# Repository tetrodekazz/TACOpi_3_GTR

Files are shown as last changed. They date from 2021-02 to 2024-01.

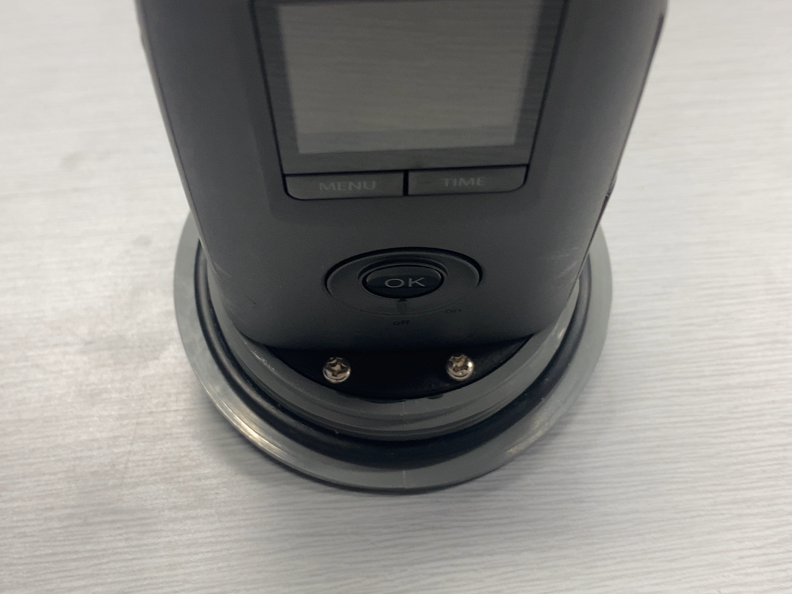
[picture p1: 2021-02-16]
screws_to_fix_camera.jpg

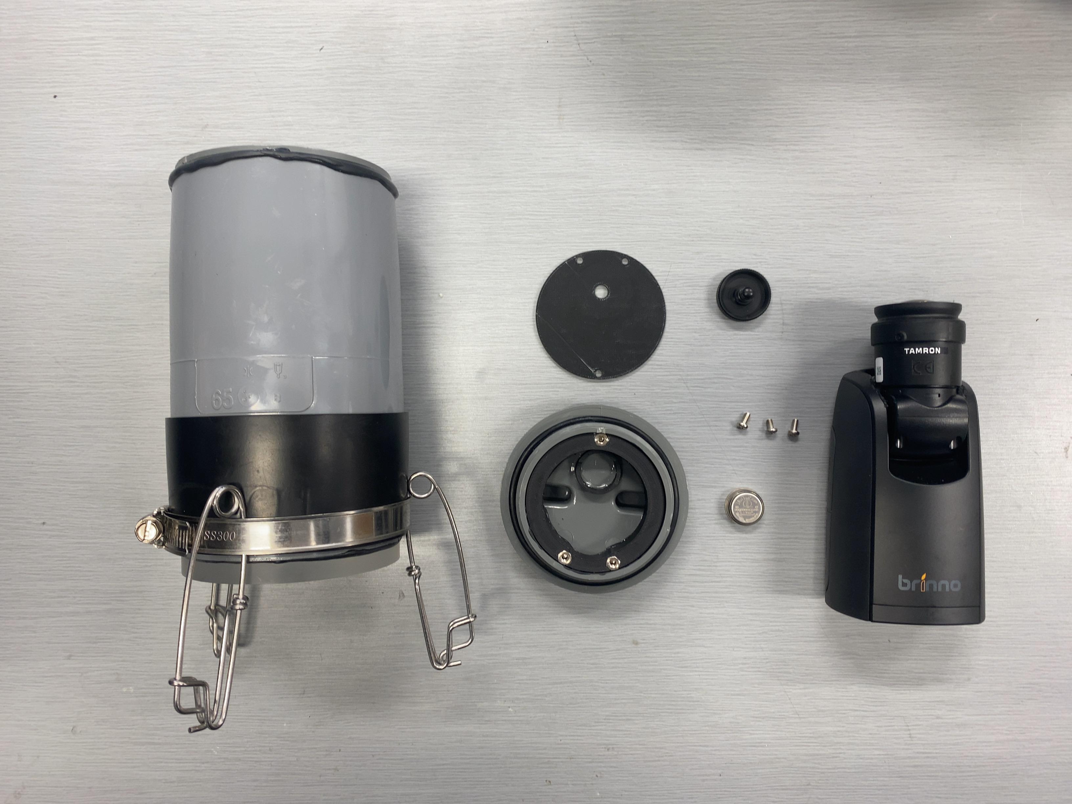
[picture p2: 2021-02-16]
all_parts.jpg

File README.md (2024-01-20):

# TACOpi_3_GTR
「TACOpi 3 GTR」は、ミズダコ漁のモニタリングのために開発された時系列撮影カメラです。
本当の名前は「Transportable Automatic Camera Observatory for Picture Integration ver.3 with a Generic Temperature Recorder」といいますが、長いのでタコパイと呼ばれています。

タコパイは、元々はRaspberry piとカメラモジュールを使用した動画撮影カメラでしたが、漁師さんが手軽に扱えることと、夜間を除き30秒間隔の時系列スチル撮影を2週間以上行えることを開発の目標としたため、途中市販の時系列カメラに載せ替え、耐圧容器も簡便化しました。

この耐圧容器は、手塚（2018）によって発表されたものの部品を変更して小型化したものですが、JAMSTECの中型高圧試験水槽で耐圧試験を行い、水深50mでも圧壊や水漏れを起こさないことが確認されています。実際に、複数回モニタリング調査に用いましたが、これまでに破損したものは皆無でした。

タコパイの製作に関する情報をオープンソースとして公開いたします。ご参考までに、部品リスト、写真のほか、3Dプリンタによる出力が必要な部品の3D CADデータを掲載します。製作方法は後ほどupload予定です（小栗一将）。

なお、タコパイの開発は文部科学省「東北マリンサイエンス拠点形成事業（海洋生態系の調査研究）」（Grant number JPMXD1111105259; https://www.jamstec.go.jp/i-teams/ ）の助成を受け行われました。

引用：手塚尚明（2018）防水ハウジング　塩ビ配管用品で防水ハウジングを作ってみましょう. http://feis.fra.affrc.go.jp/seika/tayousei/fishdiv/housing.html

小栗一将（南デンマーク大学/海洋研究開発機構）

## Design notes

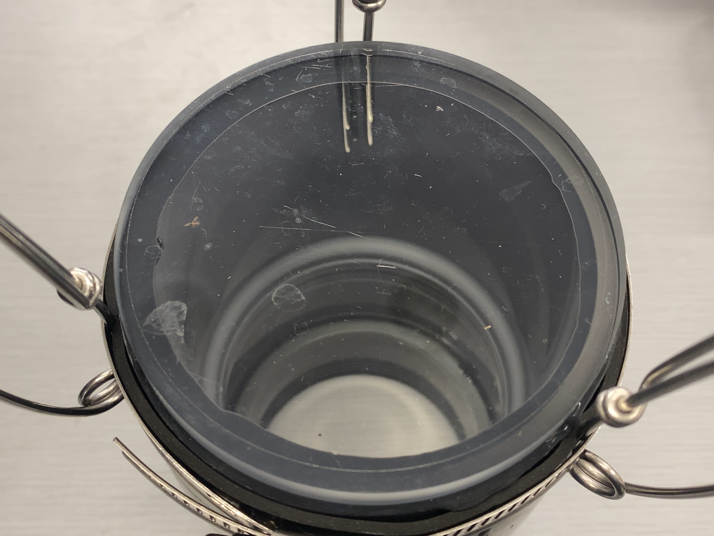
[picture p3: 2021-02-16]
front.jpg

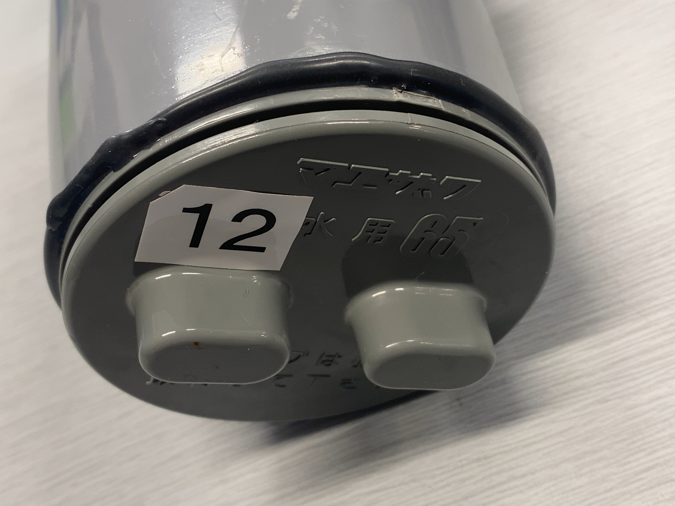
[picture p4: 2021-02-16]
lid.jpg

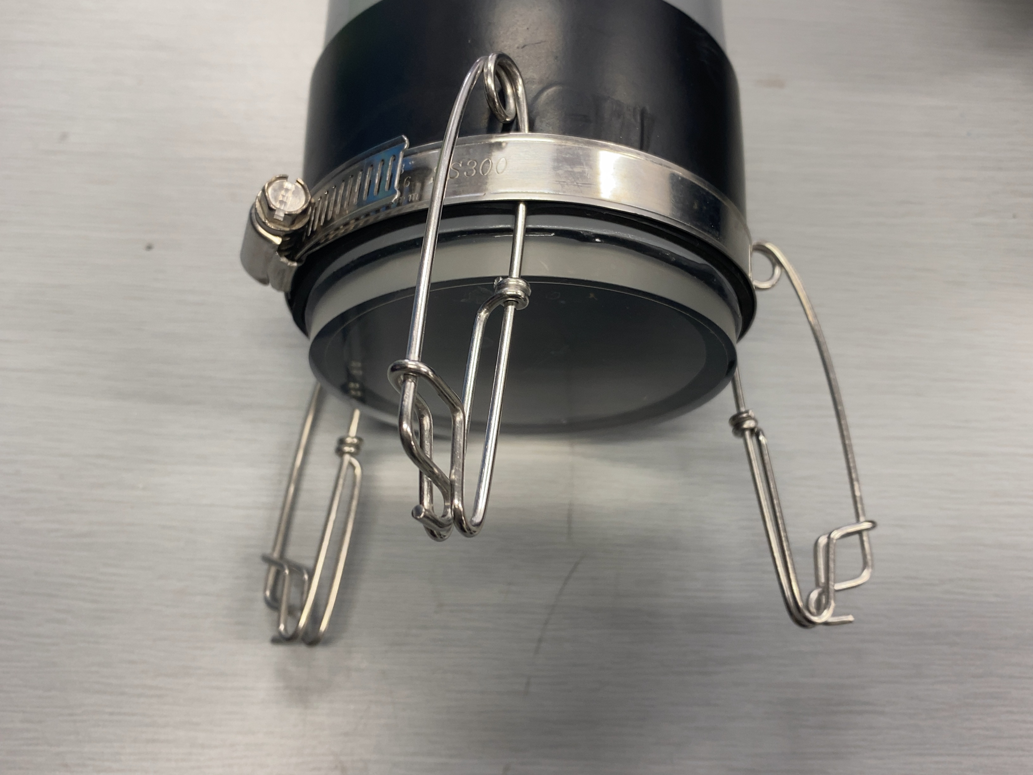
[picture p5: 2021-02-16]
hooks.jpg

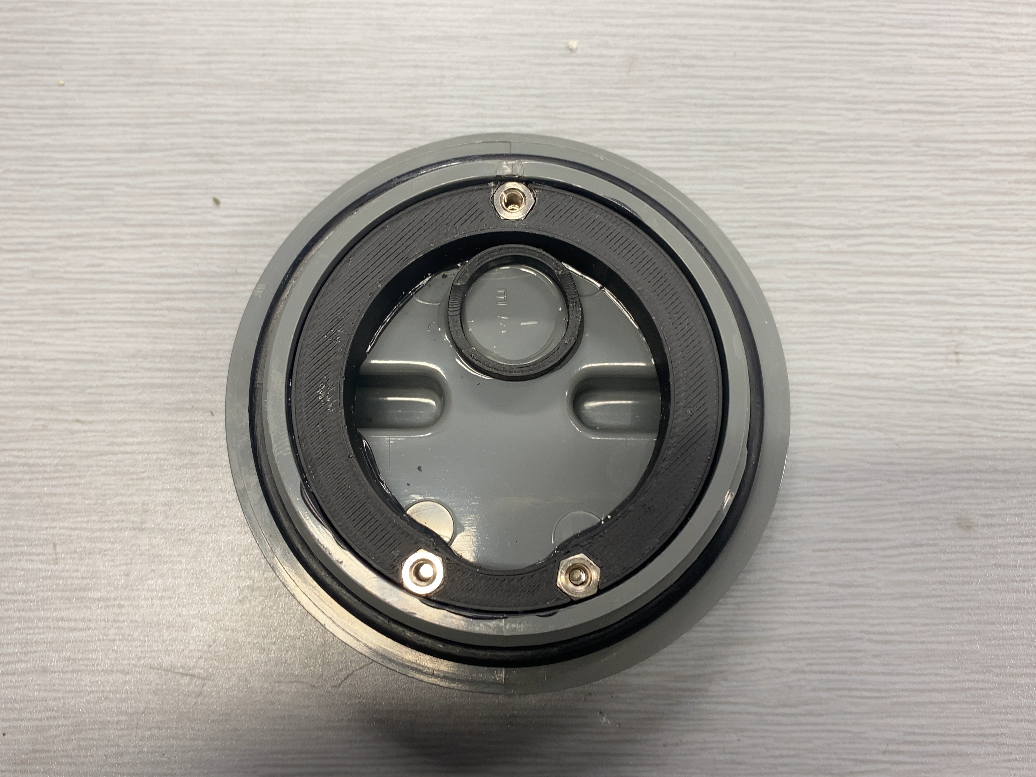
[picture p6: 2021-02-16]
lid_behind.jpg

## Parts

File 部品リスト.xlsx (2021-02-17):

TACOpi 3 GTR 部品表
部品 | 型番 | 1台あたり必要個数 | メーカー | 備考
カメラ | TCL200pro | 1 | Brinno
SDカード | 最大32GBytesまで | 1 | 各社 | 画像が8GBytes未満の場合不要。
超広角レンズ | 13FM28IR | 1 | タムロン | 広角視野が必要な場合、付属レンズと交換する。取り付けの際にカメラ筐体を削る必要がある。
温度ロガー | DS1922L | 1 | Maxim Integrated
温度ロガー設定・データ読み出し器 | DS1402D-DR8+ | 1 | Maxim Integrated
同 USBアダプタ | DS9490R | 1 | Maxim Integrated
温度ロガー用ソフトウェア | OneWireViewer | 1 | Maxim Integrated | 同社サイトよりダウンロード。java環境が必要。
TS継手ソケット | 呼び径65 | 1 | 前澤化成工業 | 前澤化成工業製を使用すること。
掃除口MCO | 呼び径65 | 1 | 前澤化成工業 | 前澤化成工業製を使用すること。
透明アクリル円板 | t=8mm、85Φ | 1 |  | アクリル加工業者にセミオーダー製作。
接着剤 | セメダインスーパーX | 1 | セメダイン
皿ネジ | M3x4 | 3
鍋ネジ | M3x6 | 3
金属スペーサー | ASB-310E | 3 | 廣杉計器 | M3x10。同等品可。
カメラ固定ネジ | E-6600 | 1 | エツミ
ブラケットピン | AK6036 | 3 | 浅野金属工業 | ステンレス製。同等品可。
ホースバンド | TA13-012 | 1 | TRUSCO | ステンレス製。最大径102mm。同等品可。
天然ゴムロール | BR-07 | 1 | 和気産業 | 長さ1m、厚さ2mm。同等品可。
オイルコンパウンド | HIVAC-G, 50 g | 1 | 信越化学工業 | Oリングに塗布。Oリングと接合面は常に清潔に。
カメラ取付土台部品1 | TACOpi_3_base_fisheye_part1.stl | 1 |  | 3Dプリンタによる出力。
カメラ取付土台部品2 | TACOpi_3_base_fisheye_part2.stl | 1 |  | 3Dプリンタによる出力。
温度ロガーホルダ | TACOpi_3_Thermocron.stl | 1 |  | 3Dプリンタによる出力。

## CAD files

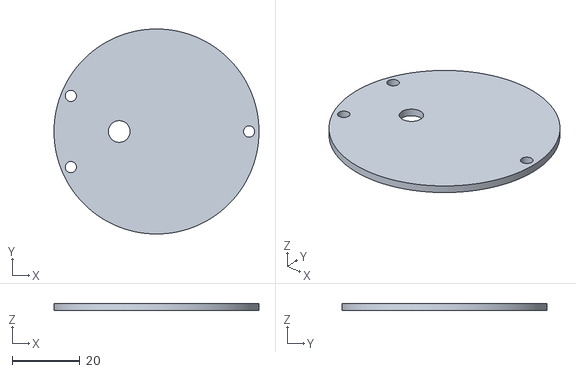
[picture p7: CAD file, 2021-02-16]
TACOpi_3_base_fisheye_part2.stl
60.5 x 60.5 x 2.00

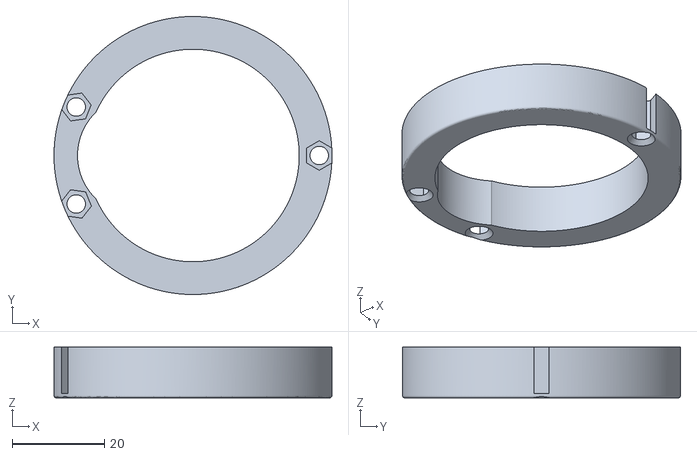
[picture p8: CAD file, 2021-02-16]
TACOpi_3_base_fisheye_part1.stl
60.2 x 60.2 x 11.0

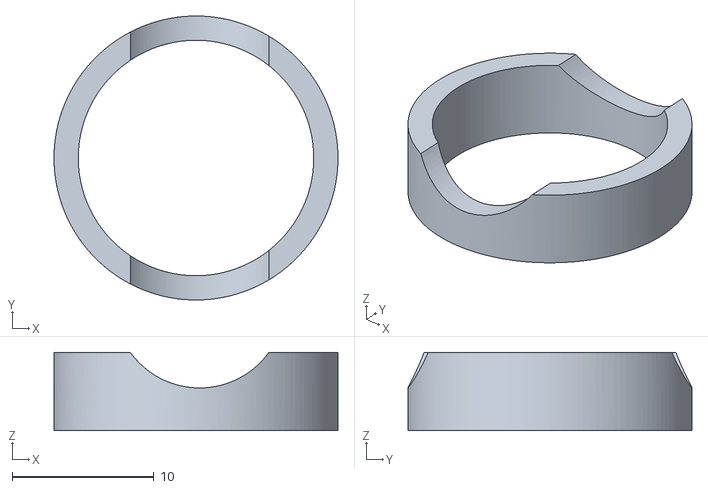
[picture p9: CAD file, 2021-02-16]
TACOpi_3_Thermocron.stl
20.0 x 20.0 x 5.50
